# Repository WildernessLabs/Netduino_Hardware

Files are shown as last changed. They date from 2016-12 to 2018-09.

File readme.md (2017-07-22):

# Legacy Netduino 1, Mini, Netduino 2 and Netduino 3 Hardware Source Files

This repo contains the schematic and PCB design files for the legacy Netduino 1, Mini, Netduino 2 and Netduino 3 hardware:

* [Netduino 1](N1)
* [Netduino 1 Plus](N1_Plus)
* [Netduino Mini](Mini)
* [Netduino 2](N2)
* [Netduino Plus 2](N2_Plus)
* [Netduino 3](N3)
* [Netduino 3 w/Ethernet](N3_Ethernet)
* [Netduino 3 w/WiFi](N3_WiFi)
 
Each directory includes: 
 * `_ASSEMBLY` Directory - Files needed of a PCB assembler to instruct their "Pick and Place" machine to assemble the components on the PCB board. Also includes the Bill of Materials (BoM) for board.
 * `_FAB` Directory - Files necessary for a PCB fabricator to assembly the PCB, including the copper masks, silkscreen art, drill templates, etc.
 * `[model].pdf` - A PDF of the board design schematic.
 * `[model].brd` - The PCB design source file. Can be opened in Allegro Cadence, or similar.

# License
Copyright 2017, Wilderness Labs Inc.
    
    Licensed under the Apache License, Version 2.0 (the "License");
    you may not use this file except in compliance with the License.
    You may obtain a copy of the License at
    
      http://www.apache.org/licenses/LICENSE-2.0
    
    Unless required by applicable law or agreed to in writing, software
    distributed under the License is distributed on an "AS IS" BASIS,
    WITHOUT WARRANTIES OR CONDITIONS OF ANY KIND, either express or implied.
    See the License for the specific language governing permissions and
    limitations under the License.

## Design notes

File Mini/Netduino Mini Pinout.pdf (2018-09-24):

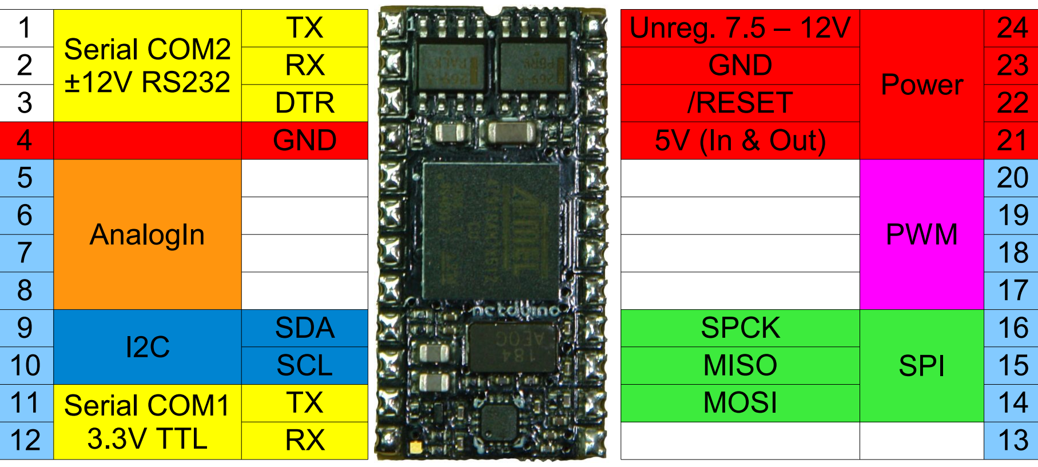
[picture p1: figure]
Unreg. 7.5 – 12V; Power; GND; DTR; /RESET; 5V (In & Out); AnalogIn; PWM; SDA; SPCK; SPI; SCL; MISO; MOSI; Serial COM2 ±12V RS232; Serial COM1 3.3V TTL

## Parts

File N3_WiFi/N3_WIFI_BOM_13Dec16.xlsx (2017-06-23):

Netduino 3 Wi-Fi Revised: Wednesday, February 25, 2015
CW0058 Revision: A
Bill Of Materials February 26,2015 22:46:41 | Page1
Item | Quantity | Reference | Manufacturer | Part Number | Description | Value | Task
1 | 1 | C1 | Murata Electronics North America | GRM31CR61A226ME19L | CAP CER 22UF 10V 20% X5R 1206 | 22uF
2 | 1 | C2 | Murata Electronics North America | GRM21BR61E106KA73L | CAP CER 10UF 25V 10% X5R 0805 | 10uF
3 | 3 | C4,C42,C47 | Murata Electronics North America | GRM21BR60J226ME39L | CAP CER 22UF 6.3V 20% X5R 0805 | 22uF
4 | 11 | C5,C6,C10,C11,C12,C13,C14,C22,C48,C49,C50 | Murata Electronics North America | GRM155R61A104KA01D | CAP CER 0.1UF 10V 10% X5R 0402 | 0.1uF
5 | 1 | C7 | Murata Electronics North America | GNM1M2R60J105ME12D | CAP ARRAY 1.0UF 6.3V X5R 0504 | 1uF
6 | 2 | C9, C53 | Murata Electronics North America | GRM033R61A104KE15D | CAP CER 0.1UF 10V X5R 0201 | 0.1uF | update
7 | 2 | C16,C17 | Murata Electronics North America | GRM155R60J225ME15D | CAP CER 2.2UF 6.3V 20% X5R 0402 | 2.2uF
8 | 2 | C18,C19 | Murata Electronics North America | GRM1555C1H180JA01D | CAP CER 18PF 50V 5% NP0 0402 | 18pF
9 | 1 | C20 | Murata Electronics North America | GRM155R71H472KA01D | CAP CER 4700PF 50V 10% X7R 0402 | 4.7nF
10 | 3 | C21,C51,C52 | Vishay | TR3C107K010C0100 | CAP TANT 100UF 10V 10% 2312 | 100uF
11 | 1 | C43 | AVX Corporation | F931A476MBA | CAP TANT 47UF 10V 1OHM 20% 1411 | 47uF
12 | 1 | C44 | Murata Electronics North America | GJM1555C1H1R0BB01D | CAP CER 1PF 50V NP0 0402 | 1pF
13 | 1 | D1 | Lite-On Inc | LTW-170TK | LED WHITE YELLOW 280MCD 0805 | WHITE
14 | 1 | D2 | Lite-On Inc | LTST-C170TBKT | LED BLUE CLEAR 0805 SMD | BLUE
15 | 1 | D3 | Micro Commerical Co | SS15E-TP | DIODE SCHOTTKY 50V 1A SMAE | SS15E-TP
16 | 1 | D4 | Littelfuse Inc | SP3003-04XTG | TVS ARRAY ESD 4CH 0.65PF SOT563 | SP3003-04XTG
17 | 3 | D5,D6,D7 | Lite-On Inc | LTST-C190TBKT | LED 468NM BLUE CLEAR 0603 SMD | BLUE
18 | 1 | D9 | Lite On | LTST-C295KGKSKT | LED GREEN YELLOW 0603 | LTST-C295KGKSKT
19 | 1 | F1 | Bourns Inc. | MF-NSMF075-2 | PTC RESETTABLE .75A 6V 1206 | MF-NSMF075-2
20 | 1 | J1 | ADAM TECH | ADC-043A-1 | CONN JACK POWER 2.1MM PCB | ADC-043A-1
21 | 2 | J2,J6 | Custom | HDR100IMP08F-G-V-TH-BLUE | CONN HEADER BLUE FEMALE 8POS .1" GOLD | HDR100IMP08F-G-V-TH-BLUE
22 | 1 | J3 | Custom | HDR100IMP10F-G-V-TH-BLUE | CONN HEADER BLUE FEMALE 10POS .1" GOLD | HDR100IMP10F-G-V-TH-BLUE
23 | 1 | J4 | Custom | HDR100IMP06F-G-V-TH-BLUE | CONN HEADER BLUE FEMALE 6POS .1" GOLD | HDR100IMP06F-G-V-TH-BLUE
24 | 1 | J5 | JAE Electronics | DX4R005JJ2R1800 | CONN RCPT MICRO USB 2.0 B | DX4R005JJ2R1800
25 | 1 | J7 | FCI | 67996-206HLF | CONN HEADER 6POS .100 STR 15AU | 67996-206HLF
26 | 1 | J8 |  | MINI_JTAG_SMD | MINI JTAG CONN HEADER 10POS UNSHD VERT SMD | MINI_JTAG_SMD | DO NOT PLACE
27 | 1 | J9 | Hirose Electric Co Ltd | DM3AT-SF-PEJM5 | CONN MICRO SD R/A PUSH-PUSH SMD | DM3AT-SF-PEJM5
28 | 3 | J10,J11,J12 | SECRET LABS | HDR050IDC10MS2-G-V-SM-BLUE | GOPORT SOCKET BLUE IDC | HDR050IDC10MS2-G-V-SM-BLUE
29 | 1 | J13 | Taiyo Yuden | AH316M245001-T | ANT BLUETOOTH W-LAN ZIGBEE WIMAX | AH316M245001-T
30 | 1 | L1 | Murata Electronics North America | LQH3NPN2R2NM0L | INDUCTOR 2.2UH 1.6A 30% 1212 | 2.2uH
31 | 1 | L2 | Murata Electronics North America | BLM15AX102SN1D | FERRITE CHIP 1000 OHM 0402 | BEAD
32 | 1 | L3 | Murata Electronics North America | LQP15MN3N6B02D | FIXED IND 3.6NH 170MA 500 MOHM | 3.6nH
33 | 6 | Q1,Q2,Q6,Q10,Q11,Q12 | ON Semiconductor | MUN5215DW1T1G | TRANS PREBIAS 10K 50V DUAL NPN SOT363 | MUN5215DW1T1G
34 | 1 | Q3 | ON Semiconductor | NTR4101PT1G | MOSFET P-CH 20V 1.8A SOT-23 | NTR4101PT1G
35 | 5 | Q4,Q5,Q7,Q8,Q9 | ON Semiconductor | NTJD4152PT1G | MOSFET 2P-CH 20V 880MA SOT-363 | NTJD4152PT1G
36 | 1 | R1 | Panasonic - ECG | EXB-N8V102JX | RES ARRAY 1K OHM 4 RES 0804 | 1K
37 | 1 | R3 | Panasonic - ECG | ERJ-2GEJ152X | RES 1.5K OHM 1/10W 5% 0603 SMD | 1.5K | Update
38 | 5 | R4,R5,R11,R12,R14 | Panasonic - ECG | EXB-N8V103JX | RES ARRAY 10K OHM 4 RES 0804 | 10K
39 | 1 | R6 | Panasonic - ECG | ERJ-2RKF1542X | RES 15.4K OHM 1/10W 1% 0402 SMD | 15.4K
40 | 1 | R7 | Panasonic - ECG | ERJ-2GEJ391X | RES 390 OHM 1/10W 5% 0402 SMD | 390
41 | 1 | R8 | Panasonic - ECG | EXB-24V104JX | RES ARRAY 100K OHM 2 RES 0404 | 100K
42 | 1 | R9 | Panasonic - ECG | EXB-24V220JX | RES ARRAY 22 OHM 2 RES 0404 | 22
43 | 1 | R10 | Panasonic - ECG | ERJ-2RKF1004X | RES 1.00M OHM 1/10W 1% 0402 SMD | 1M
44 | 1 | R13 | Panasonic - ECG | EXB-24V103JX | RES ARRAY 10K OHM 2 RES 0404 | 10K
45 | 1 | R15 | Panasonic - ECG | EXB-N8V681JX | RES ARRAY 680 OHM 4 RES 0804 | 680
46 | 1 | R16 | Panasonic - ECG | EXB-24V152JX | RES ARRAY 1.5K OHM 2 RES 0404 | 1.5K
47 | 1 | R18 | Panasonic - ECG | ERJ-2RKF1003X | RES 100K OHM 1/10W 1% 0402 SMD | 100K
48 | 1 | SW1 | HUA-JIE | TSXH-2GL | SWITCH TACTILE SPST-NO | TSXH-2GL
49 | 1 | U1 | Texas Instruments | LM3671MF-3.3/NOPB | IC REG BUCK SYNC 3.3V SOT23-5 | LM3671MF-3.3/NOPB
50 | 1 | U2 | Texas Instruments | TLV1117-50IKVURG3 | IC REG LDO 5V 0.8A TO252-3 | TLV1117-50IKVURG3
51 | 1 | U3 | Texas Instruments | LMV321IDCKR | IC OPAMP GP 1MHZ RRO SC70-5 | LMV321IDCKR
52 | 1 | U4 | STMicroelectronics | STM32F427VIT6 | IC MCU ARM 2MB FLASH 100LQFP | STM32F427VIT6
53 | 1 | U5 | Texas Instruments | CC3100MOD | MODULE WI-FI NETWORK PROCESSOR | CC3100MOD
54 | 1 | Y1 | Abracon Corporation | ABM7-25.000MHZ-D2Y-T | CRYSTAL 25.000 MHZ 18PF SMD | 25.000MHz

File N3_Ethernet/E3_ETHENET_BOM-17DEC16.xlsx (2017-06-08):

Netduino 3 Ethernet Revised: Monday, January 12, 2015
CW0053 Revision: A
Bill Of Materials January 15,2015 13:19:47 | Page1
Item | Quantity | Reference | Manufacturer | Part Number | Description | Value | Notes
1 | 1 | C1 | Murata Electronics North America | GRM31CR61A226ME19L | CAP CER 22UF 10V 20% X5R 1206 | 22uF
2 | 1 | C2 | Murata Electronics North America | GRM21BR61E106KA73L | CAP CER 10UF 25V 10% X5R 0805 | 10uF
3 | 4 | C4,C23,C25,C42 | Murata Electronics North America | GRM21BR60J226ME39L | CAP CER 22UF 6.3V 20% X5R 0805 | 22uF
4 | 10 | C5,C6,C10,C11,C12,C13,C14,C22,C29,C33 | Murata Electronics North America | GRM155R61A104KA01D | CAP CER 0.1UF 10V 10% X5R 0402 | 0.1uF
5 | 1 | C7 | Murata Electronics North America | GNM1M2R60J105ME12D | CAP ARRAY 1.0UF 6.3V X5R 0504 | 1uF
6 | 16 | C9,C24,C26,C30,C31,C32,C35,C39, C44,C45,C46,C47,C48,C49,C50,C51 | Murata Electronics North America | GRM033R61A104KE15D (http://www.mouser.com/ProductDetail/Murata-Electronics/GRM033R61A104KE15D/) | CAP CER 0.1UF 10V X5R 0201 | 0.1uF
7 | 2 | C16,C17 | Murata Electronics North America | GRM155R60J225ME15D | CAP CER 2.2UF 6.3V 20% X5R 0402 | 2.2uF
8 | 4 | C18,C19,C37,C38 | Murata Electronics North America | GRM1555C1H180JA01D | CAP CER 18PF 50V 5% NP0 0402 | 18pF
9 | 1 | C20 | Murata Electronics North America | GRM155R71H472KA01D | CAP CER 4700PF 50V 10% X7R 0402 | 4.7nF
10 | 1 | C21 | Vishay | TR3C107K010C0100 | CAP TANT 100UF 10V 10% 2312 | 100uF
11 | 3 | C27,C34,C36 | Murata Electronics North America | GRM188R60J475KE19D | CAP CER 4.7UF 6.3V 10% X5R 0603 | 4.7uF
12 | 1 | C28 | Murata Electronics North America | GRM155R61A105KE15D | CAP CER 1UF 10V 10% X5R 0402 | 1uF
13 | 1 | C40 | AVX Corporation | 1206GC102KAT1A | CAP CERM 1000PF 2000V X7R 1206 | 1nF
14 | 1 | C41 | Murata Electronics North America | GRM21BR71H104KA01L | CAP CER 0.1UF 50V 10% X7R 0805 | 0.1uF
15 | 1 | C43 | AVX Corporation | F931A476MBA | CAP TANT 47UF 10V 1OHM 20% 1411 | 47uF
16 | 1 | D1 | Lite-On Inc | LTW-170TK | LED WHITE YELLOW 280MCD 0805 | WHITE
17 | 1 | D2 | Lite-On Inc | LTST-C170TBKT | LED BLUE CLEAR 0805 SMD | BLUE
18 | 1 | D3 | Micro Commerical Co | SS15E-TP | DIODE SCHOTTKY 50V 1A SMAE | SS15E-TP
19 | 2 | D4,D8 | Littelfuse Inc | SP3003-04XTG | TVS ARRAY ESD 4CH 0.65PF SOT563 | SP3003-04XTG
20 | 3 | D5,D6,D7 | Lite-On Inc | LTST-C190TBKT | LED 468NM BLUE CLEAR 0603 SMD | BLUE
21 | 1 | D9 | Lite On | LTST-C295KGKSKT | LED GREEN YELLOW 0603 | LTST-C295KGKSKT
22 | 1 | F1 | Bourns Inc. | MF-NSMF075-2 | PTC RESETTABLE .75A 6V 1206 | MF-NSMF075-2
23 | 1 | J1 | ADAM TECH | ADC-043A-1 | CONN JACK POWER 2.1MM PCB | ADC-043A-1
24 | 2 | J2,J6 | Custom | HDR100IMP08F-G-V-TH-BLUE | CONN HEADER BLUE FEMALE 8POS .1" GOLD | HDR100IMP08F-G-V-TH-BLUE
25 | 1 | J3 | Custom | HDR100IMP10F-G-V-TH-BLUE | CONN HEADER BLUE FEMALE 10POS .1" GOLD | HDR100IMP10F-G-V-TH-BLUE
26 | 1 | J4 | Custom | HDR100IMP06F-G-V-TH-BLUE | CONN HEADER BLUE FEMALE 6POS .1" GOLD | HDR100IMP06F-G-V-TH-BLUE
27 | 1 | J5 | JAE Electronics | DX4R005JJ2R1800 | CONN RCPT MICRO USB 2.0 B | DX4R005JJ2R1800
28 | 1 | J7 | FCI | 67996-206HLF | CONN HEADER 6POS .100 STR 15AU | 67996-206HLF | DO NOT PLACE
29 | 1 | J8 |  | MINI_JTAG_SMD | MINI JTAG CONN HEADER 10POS UNSHD VERT SMD | MINI_JTAG_SMD | DO NOT PLACE
30 | 1 | J9 | Hirose Electric Co Ltd | DM3AT-SF-PEJM5 | CONN MICRO SD R/A PUSH-PUSH SMD | DM3AT-SF-PEJM5
31 | 3 | J10,J11,J12 | SECRET LABS | HDR050IDC10MS2-G-V-SM-BLUE | GOPORT SOCKET BLUE IDC | HDR050IDC10MS2-G-V-SM-BLUE
32 | 1 | J13 | Molex | 44661-0002 | CONN MOD JACK R/A 8P8C UNSHIELDED | 44661-0002
33 | 1 | L1 | Murata Electronics North America | LQH3NPN2R2NM0L | INDUCTOR 2.2UH 1.6A 30% 1212 | 2.2uH
34 | 4 | L2,L3,L4,L5 | Murata Electronics North America | BLM15AX102SN1D | FERRITE CHIP 1000 OHM 0402 | BEAD
35 | 5 | Q1,Q2,Q6,Q10,Q11 | ON Semiconductor | MUN5215DW1T1G | TRANS PREBIAS 10K 50V DUAL NPN SOT363 | MUN5215DW1T1G
36 | 1 | Q3 | ON Semiconductor | NTR4101PT1G | MOSFET P-CH 20V 1.8A SOT-23 | NTR4101PT1G
37 | 5 | Q4,Q5,Q7,Q8,Q9 | ON Semiconductor | NTJD4152PT1G | MOSFET 2P-CH 20V 880MA SOT-363 | NTJD4152PT1G
38 | 1 | R1 | Panasonic - ECG | EXB-N8V102JX | RES ARRAY 1K OHM 4 RES 0804 | 1K
39 | 1 | R3 | Panasonic - ECG | ERJ-3EKF1501V (http://www.mouser.com/ProductDetail/Panasonic/ERJ-3EKF1501V/?qs=H7k1u0Mp9JTu8xEF0m60uQ%3D%3D) | RES 1.5K OHM 1/10W 1% 0603 SMD | 1.5K
40 | 6 | R4,R5,R11,R12,R14,R19 | Panasonic - ECG | EXB-N8V103JX | RES ARRAY 10K OHM 4 RES 0804 | 10K
41 | 1 | R6 | Panasonic - ECG | ERJ-2RKF1542X | RES 15.4K OHM 1/10W 1% 0402 SMD | 15.4K
42 | 1 | R7 | Panasonic - ECG | ERJ-2GEJ391X | RES 390 OHM 1/10W 5% 0402 SMD | 390
43 | 1 | R8 | Panasonic - ECG | EXB-24V104JX | RES ARRAY 100K OHM 2 RES 0404 | 100K
44 | 1 | R9 | Panasonic - ECG | EXB-24V220JX | RES ARRAY 22 OHM 2 RES 0404 | 22
45 | 3 | R10,R16,R20 | Panasonic - ECG | ERJ-2RKF1004X | RES 1.00M OHM 1/10W 1% 0402 SMD | 1M
46 | 1 | R13 | Panasonic - ECG | EXB-24V103JX | RES ARRAY 10K OHM 2 RES 0404 | 10K
47 | 1 | R15 | Panasonic - ECG | EXB-N8V681JX | RES ARRAY 680 OHM 4 RES 0804 | 680
48 | 1 | R17 | Vishay Dale | CRA06S08349R9FTA | RES ARRAY 49.9 OHM 4 RES 1206 | 49.9
49 | 1 | R18 | Vishay Dale | CRA06S08375R0FTA | RES ARRAY 75 OHM 4 RES 1206 | 75
50 | 1 | R21 | Panasonic - ECG | ERJ-2RKF1212X | RES 12.1K OHM 1/10W 1% 0402 SMD | 12.1K
51 | 1 | R22 | Panasonic - ECG | EXB-24V152JX | RES ARRAY 1.5K OHM 2 RES 0404 | 1.5K
52 | 1 | SW1 | HUA-JIE | TSXH-2GL | SWITCH TACTILE SPST-NO | TSXH-2GL
53 | 1 | T1 | Pulse | HX1198NLT | MODULE XFRMR SGL ETHR LAN 16SOIC | HX1198NLT
54 | 1 | U1 | Texas Instruments | LM3671MF-3.3/NOPB | IC REG BUCK SYNC 3.3V SOT23-5 | LM3671MF-3.3/NOPB
55 | 1 | U2 | Texas Instruments | TLV1117-50IKVURG3 | IC REG LDO 5V 0.8A TO252-3 | TLV1117-50IKVURG3
56 | 1 | U3 | Texas Instruments | LMV321IDCKR | IC OPAMP GP 1MHZ RRO SC70-5 | LMV321IDCKR
57 | 1 | U4 | STMicroelectronics | STM32F427VIT6 | IC MCU ARM 2MB FLASH 100LQFP | STM32F427VIT6
58 | 1 | U5 | Asix | AX88796CLF | Low-Power SPI or Non-PCI Ethernet Controller | AX88796CLF
59 | 2 | Y1,Y2 | Abracon Corporation | ABM7-25.000MHZ-D2Y-T | CRYSTAL 25.000 MHZ 18PF SMD | 25.000MHz

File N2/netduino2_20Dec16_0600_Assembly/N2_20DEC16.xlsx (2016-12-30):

Netduino 2 Revised: 20DEC2016
CW0035 Revision: A
Bill Of Materials October 16,2012 13:13:13 | Page1
Item | Quantity | Reference | Manufacturer | Part Number | Description | Task
______________________________________________
1 | 1 | C1 | Murata Electronics North America | GRM21BR71H474KA88L | CAP CER 0.47UF 50V 10% X7R 0805
2 | 9 | C2,C5,C6,C7,C8,C15,C16,C17,C26 | Murata Electronics North America | GRM31CR71A106KA01L | CAP CER 10UF 10V 10% X7R 1206
3 | 10 | C3,C4,C9,C10,C11,C12,C13,C14,C20,C22 | Murata Electronics North America | GRM188R71C104KA01D | CAP CER 0.1UF 16V 10% X7R 0603
4 | 2 | C18,C19 | Murata Electronics North America | GRM21BR71A225KA01L | CAP CER 2.2UF 10V 10% X7R 0805
5 | 1 | C21 | Murata Electronics North America | GRM21BR71A105KA01L | CAP CER 1UF 10V 10% X7R 0805
6 | 2 | C23,C24 | Murata Electronics North America | GRM1885C1H180JA01D | CAP CER 18PF 50V 5% NP0 0603
7 | 1 | C25 | Vishay | TR3C107K010C0100 | CAP TANT 100UF 10V 10% 2312
8 | 1 | D1 | Micro Commerical Co | SS15-TP | DIODE SCHOTTKY 1A 50V SMA
9 | 1 | D2 | Lite-On Inc | LTW-170TK | LED WHITE YELLOW 280MCD 0805
10 | 1 | D3 | Lite-On Inc | LTST-C170TBKT | LED BLUE CLEAR 0805 SMD
11 | 3 | D4,D5,D6 | Littelfuse Inc | PGB1010402KR | SUPPRESSOR ESD 12VDC 0402 SMD
12 | 1 | F1 | Littelfuse | 1206L050YR | THERMISTOR PTC 6V .50A RESETTABLE
13 | 1 | J1 | ADAM TECH | ADC-002A-1 | CONN JACK POWER 2.1MM PCB
14 | 2 | J2,J6 | Custom | HDR100IMP08F-G-V-TH-BLUE | CONN HEADER BLUE FEMALE 8POS .1" GOLD
15 | 1 | J3 | Hirose | 656-DX4R005JJ2R1800 (http://www.mouser.com/ProductDetail/JAE-Electronics/DX4R005JJ2R1800/?qs=ckml%252bxrUdjTvILfne%252b8EpQ%3D%3D) | Micro USB 2.0 Type B Connectors | Updated
16 | 1 | J4 | Custom | HDR100IMP10F-G-V-TH-BLUE | CONN HEADER BLUE FEMALE 10POS .1" GOLD
17 | 1 | J5 | Custom | HDR100IMP06F-G-V-TH-BLUE | CONN HEADER BLUE FEMALE 6POS .1" GOLD
18 | 1 | L1 | Murata Electronics North America | LQH3NPN2R2NM0L | INDUCTOR 2.2UH 1.6A 30% SMD
19 | 1 | Q1 | ON Semiconductor | MMBT3906TT1G | TRANS PNP GP 40V 200MA SC75-3
20 | 2 | Q2,Q3 | ON Semiconductor | MBT3904DW1T1G | TRANS NPN DUAL 40V 200MA SOT-363
21 | 1 | Q4 | ON Semiconductor | NTR4101PT1G | MOSFET P-CH 20V 1.8A SOT-23
22 | 1 | Q5 | ON Semiconductor | NTJD4152PT1G | MOSFET 2P-CH 20V 880MA SOT-363
23 | 1 | R2 | Panasonic - ECG | ERJ-3EKF1501V | RES 1.50K OHM 1/10W 1% 0603 SMD
24 | 1 | R3 | Panasonic ECG | ERJ-6GEYJ1R0V | RESISTOR 1.0 OHM 1/8W 5% 0805
25 | 3 | R4,R11,R12 | Panasonic - ECG | EXB-N8V103JX (http://www.mouser.com/ProductDetail/Panasonic/EXB-N8V103JX/?qs=u8huD7HxK6bNr8tqvNkAOQ%3D%3D) | RES ARRAY 10K OHM 4 RES 0804 | Updated
26 | 1 | R6 | Panasonic - ECG | ERJ-3EKF1001V | RES 1.00K OHM 1/10W 1% 0603 SMD
27 | 1 | R8 | Panasonic - ECG | ERJ-2RKF1402X (http://www.mouser.com/ProductDetail/Panasonic/ERJ-2RKF1402X/?qs=MVjVSMjNRMrMgFTFLdW36A%3D%3D) | RES 14.0K OHM 1/10W 1% 0402 SMD | Updated
28 | 1 | R9 | Panasonic - ECG | ERJ-2RKF1623X (http://www.mouser.com/ProductDetail/Panasonic/ERJ-2RKF1623X/?qs=xvTjQbhLFHK1fJJgOidlhQ%3D%3D) | RES 162K OHM 1/10W 1% 0402 SMD
29 | 1 | R10 | Panasonic - ECG | ERJ-2RKF3602X (http://www.mouser.com/ProductDetail/Panasonic/ERJ-2RKF3602X/?qs=YMBIwoNQYdWglRbBHPFpuA%3D%3D) | RES 36.0K OHM 1/10W 1% 0402 SMD | Updated
30 | 1 | R13 | Panasonic - ECG | ERJ-2GEJ391X (http://www.mouser.com/ProductDetail/Panasonic/ERJ-2GEJ391X/?qs=H7k1u0Mp9JQHgGq8tq8dsw%3D%3D) | RES 390 OHM 1/10W 5% 0402 SMD | Updated
31 | 1 | R14 | Panasonic - ECG | EXB-24V220JX (http://www.mouser.com/ProductDetail/Panasonic/EXB-24V220JX/?qs=oE3VwAv%2FYtkKhK0m4TkqFQ%3D%3D) | RES ARRAY 22 OHM 2 RES 0404 | Updated
32 | 4 | R27,R28,R31,R32 | Panasonic - ECG | ERJ-3EKF1002V | RES 10.0K OHM 1/10W 1% 0603 SMD
33 | 1 | SW1 | HUA-JIE | TSXH-2GL | SWITCH TACTILE SPST-NO | Updated
34 | 1 | U1 | ON Semiconductor | MC33269DT-5.0G | IC REG LDO 800MA 5V DPAK
35 | 1 | U2 | STMicroelectronics | ST1S12GR | IC BUCK SYNC ADJ 0.7A TSOT23
36 | 1 | U3 | National Semiconductor | LMV7271MF/NOPB | IC COMP 1.8V SNGL R-R IN SOT23-5
37 | 1 | U4 | STMicroelectronics | STM32F205RFT6 | MCU ARM 768KB FLASH 64LQFP
38 | 1 | Y1 | Abracon Corporation | ABM3B-25.000MHZ-D2Y-T | CRYSTAL 25.000 MHZ 18PF SMD

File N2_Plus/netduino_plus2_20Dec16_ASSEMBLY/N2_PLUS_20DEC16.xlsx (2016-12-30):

Netduino Plus 2 Revised: December 20 2016
CW0034 Revision: A
Bill Of Materials September 28,2012 9:20:16 | Page1
Item | Quantity | Reference | Manufacturer | Part Number | Description | Task
______________________________________________
1 | 1 | C1 | Murata Electronics North America | GRM21BR71H474KA88L | CAP CER 0.47UF 50V 10% X7R 0805
2 | 11 | C2,C5,C6,C7,C8,C15,C16,C17,C26,C27,C34 | Murata Electronics North America | GRM31CR71A106KA01L | CAP CER 10UF 10V 10% X7R 1206
3 | 18 | C3,C4,C9,C10,C11,C12,C13,C14,C20,C22,C28,C29,C30,C31,C32,C33,C35,C36 | Murata Electronics North America | GRM155R61A104KA01D | CAP CER 0.1UF 10V 10% X5R 0402
4 | 2 | C18,C19 | Murata Electronics North America | GRM21BR71A225KA01L | CAP CER 2.2UF 10V 10% X7R 0805
5 | 1 | C21 | Murata Electronics North America | GRM155R60J105KE19D | CAP CER 1UF 6.3V 10% X5R 0402
6 | 2 | C23,C24 | Murata | GRM1555C1H180JA01D (http://www.mouser.com/ProductDetail/Murata-Electronics/GRM1555C1H180JA01D/?qs=mRkWMvdT7ZKEkI5QPHEfww%3D%3D) | CAP CER 18PF 50V 5% NP0 0402 | updated
7 | 1 | C25 | Vishay | TR3C107K010C0100 | CAP TANT 100UF 10V 10% 2312
8 | 1 | C37 | AVX Corporation | 1206GC102KAT1A | CAP CERM 1000PF 2000V X7R 1206
9 | 1 | D1 | Micro Commerical Co | SS15-TP | DIODE SCHOTTKY 1A 50V SMA
10 | 1 | D2 | Lite-On Inc | LTW-170TK | LED WHITE YELLOW 280MCD 0805
11 | 1 | D3 | Lite-On Inc | LTST-C170TBKT | LED BLUE CLEAR 0805 SMD
12 | 3 | D4,D5,D6 | Littelfuse Inc | PGB1010402KR | SUPPRESSOR ESD 12VDC 0402 SMD
13 | 1 | D7 | Lite-On Inc | LTST-C190KGKT | LED GREEN CLEAR 0603 SMD
14 | 1 | F1 | Littelfuse | 1206L050YR | THERMISTOR PTC 6V .50A RESETTABLE
15 | 1 | J1 | ADAM TECH | ADC-043A-1 | CONN JACK POWER 2.1MM PCB
16 | 2 | J2,J6 | Custom | HDR100IMP08F-G-V-TH-BLUE | CONN HEADER BLUE FEMALE 8POS .1" GOLD
17 | 1 | J3 | JAE Electronics | 656-DX4R005JJ2R1800 (http://www.mouser.com/ProductDetail/JAE-Electronics/DX4R005JJ2R1800/?qs=ckml%252bxrUdjTvILfne%252b8EpQ%3D%3D) | Micro USB 2.0 Type B Connectors | updated
18 | 1 | J4 | Custom | HDR100IMP10F-G-V-TH-BLUE | CONN HEADER BLUE FEMALE 10POS .1" GOLD
19 | 1 | J5 | Custom | HDR100IMP06F-G-V-TH-BLUE | CONN HEADER BLUE FEMALE 6POS .1" GOLD
20 | 1 | J7 | DO NOT PLACE | MINI_JTAG | Mini JTAG Connector TH Vertical
21 | 1 | J8 | Hirose Electric Co Ltd | DM3AT-SF-PEJ | CONN MICRO SD R/A PUSH-PUSH SMD
22 | 1 | J9 | Molex | 44661-0002 | CONN MODULAR JACK RT/ANG 8-8
23 | 1 | L1 | Murata Electronics North America | LQH3NPN2R2NM0L | INDUCTOR 2.2UH 1.6A 30% SMD
24 | 1 | L2 | Murata | BLM15AX102SN1D (http://www.mouser.com/ProductDetail/Murata-Electronics/BLM15AX102SN1D/?qs=MY6wChARw2zFsmOR09MDxg%3D%3D) | FERRITE CHIP 1000 OHM 0402 | updated
25 | 1 | Q1 | ON Semiconductor | MMBT3906TT1G | TRANS PNP GP 40V 200MA SC75-3
26 | 2 | Q2,Q3 | ON Semiconductor | MBT3904DW1T1G | TRANS NPN DUAL 40V 200MA SOT-363
27 | 1 | Q4 | ON Semiconductor | NTR4101PT1G | MOSFET P-CH 20V 1.8A SOT-23
28 | 2 | Q5,Q6 | ON Semiconductor | NTJD4152PT1G | MOSFET 2P-CH 20V 880MA SOT-363
29 | 2 | R2,R16 | Panasonic - ECG | ERJ-3EKF1501V (http://www.mouser.com/ProductDetail/Panasonic/ERJ-3EKF1501V/?qs=H7k1u0Mp9JTu8xEF0m60uQ%3D%3D) | RES 1.5K OHM 1/10W 1% 0603 SMD | updated
30 | 1 | R3 | Panasonic ECG | ERJ-6GEYJ1R0V | RESISTOR 1.0 OHM 1/8W 5% 0805
31 | 4 | R4,R7,R11,R12 | Panasonic - ECG | EXB-N8V103JX | RES ARRAY 10K OHM 4 RES 0804
32 | 6 | R5,R15,R26,R27,R28,R31 | Panasonic - ECG | ERJ-3EKF1002V (http://www.mouser.com/ProductDetail/Panasonic/ERJ-3EKF1002V/?qs=H7k1u0Mp9JSrGPQ5%2F5COuw%3D%3D) | RES 10.0K OHM 1/10W 1% 0603 SMD | updated
33 | 1 | R6 | Panasonic - ECG | ERJ-3EKF1001V (http://www.mouser.com/ProductDetail/Panasonic/ERJ-3EKF1001V/?qs=H7k1u0Mp9JTM8yQxOuvoDg%3D%3D) | RES 1.00K OHM 1/10W 1% 0603 SMD | updated
34 | 1 | R8 | Panasonic - ECG | ERJ-2RKF1402X | RES 14.0K OHM 1/10W 1% 0402 SMD
35 | 1 | R9 | Panasonic - ECG | ERJ-2RKF1623X | RES 162K OHM 1/10W 1% 0402 SMD
36 | 1 | R10 | Panasonic - ECG | ERJ-2RKF3602X | RES 36.0K OHM 1/10W 1% 0402 SMD
37 | 1 | R13 | Panasonic - ECG | ERJ-2GEJ391X | RES 390 OHM 1/10W 5% 0402 SMD
38 | 1 | R14 | Panasonic - ECG | EXB-24V220JX | RES ARRAY 22 OHM 2 RES 0404
39 | 1 | R17 | Panasonic - ECG | ERJ-2RKF2321X | RES 2.32K OHM 1/10W 1% 0402 SMD
40 | 4 | R18,R19,R20,R21 | Panasonic - ECG | ERJ-2RKF49R9X | RES 49.9 OHM 1/10W 1% 0402 SMD
41 | 4 | R22,R23,R24,R25 | Panasonic - ECG | ERJ-2RKF75R0X | RES 75.0 OHM 1/10W 1% 0402 SMD
42 | 1 | R30 | Panasonic - ECG | ERJ-2GEJ330X | RES 33 OHM 1/10W 5% 0402 SMD
43 | 1 | SW1 | HUA-JIE | TSXH-2GL | SWITCH TACTILE SPST-NO | updated
44 | 1 | T1 | Pulse | HX1198NL | MODULE XFRMR SGL ETHR LAN 16SOIC
45 | 1 | U1 | ON Semiconductor | MC33269DT-5.0G | IC REG LDO 800MA 5V DPAK
46 | 1 | U2 | STMicroelectronics | ST1S12GR | IC BUCK SYNC ADJ 0.7A TSOT23
47 | 1 | U3 | National Semiconductor | LMV7271MF/NOPB | IC COMP 1.8V SNGL R-R IN SOT23-5
48 | 1 | U4 | STMicroelectronics | STM32F405RGT6 | IC MCU 32BIT 1MB FLASH 64LQFP
49 | 1 | U5 | Microchip Technology | ENC28J60T-I/SS | IC ETHERNET CTLR SPI 28SSOP
50 | 1 | Y1 | Abracon Corporation | ABM7-25.000MHZ-D2Y-T | CRYSTAL 25.000 MHZ 18PF SMD
51 | 3 | MT1,MT2,MT3 | DO NOT PLACE

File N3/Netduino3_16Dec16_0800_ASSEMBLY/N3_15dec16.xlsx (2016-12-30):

Netduino 3 Revised: Wednesday, June 03, 2015
CW0057 Revision: A
Bill Of Materials June 3,2015 10:28:26 | Page1
Item | Quantity | Reference | Manufacturer | Part Number | Description | Value | Task
1 | 1 | C1 | Murata Electronics North America | GRM31CR61A226ME19L | CAP CER 22UF 10V 20% X5R 1206 | 22uF
2 | 1 | C2 | Murata Electronics North America | GRM21BR61E106KA73L | CER CAP 10UF 25V 10% X5R 0805 | 10uF | Updated
3 | 2 | C4,C42 | Murata Electronics North America | GRM21BR60J226ME39L | CAP CER 22UF 6.3V 20% X5R 0805 | 22uF
4 | 9 | C5,C6,C10,C11,C12,C13,C14,C46,C47 | Murata Electronics North America | GRM188R71C104KA01D | CAP CER 0.1UF 16V 10% X7R 0603 | 0.1uF
5 | 2 | C16,C17 | Murata Electronics North America | GRM188R61C225KE15D | CAP CER 2.2UF 16V 10% X5R 0603 | 2.2uF
6 | 2 | C18,C19 | Murata Electronics North America | GRM1885C1H180JA01D | CAP CER 18PF 50V 5% NP0 0603 | 18pF
7 | 1 | C20 | Murata Electronics North America | GRM155R71H472KA01D | CAP CER 4700PF 50V 10% X7R 0402 | 4.7nF | Updated
8 | 1 | C21 | Vishay | TR3C107K010C0100 | CAP TANT 100UF 10V 10% 2312 | 100uF
9 | 1 | C43 | AVX Corporation | F931A476MBA | CAP TANT 47UF 10V 1OHM 20% 1411 | 47uF
10 | 2 | C44,C45 | Murata Electronics North America | GRM155R61A105KE15D | CAP CER 1UF 10V 10% X5R 0402 | 1uF | Updated
11 | 1 | D1 | Lite-On Inc | LTW-170TK | LED WHITE YELLOW 280MCD 0805 | WHITE
12 | 1 | D2 | Lite-On Inc | LTST-C170TBKT | LED BLUE CLEAR 0805 SMD | BLUE
13 | 1 | D3 | Micro Commerical Co | SS15E-TP | DIODE SCHOTTKY 50V 1A SMAE | SS15E-TP
14 | 1 | D4 | Littelfuse Inc | SP3003-04XTG | TVS ARRAY ESD 4CH 0.65PF SOT563 | SP3003-04XTG
15 | 3 | D5,D6,D7 | Lite-On Inc | LTST-C190TBKT | LED 468NM BLUE CLEAR 0603 SMD | BLUE
16 | 1 | F1 | Bourns Inc. | MF-NSMF075-2 | PTC RESETTABLE .75A 6V 1206 | MF-NSMF075-2
17 | 1 | J1 | ADAM TECH | ADC-002A-1 | CONN JACK POWER 2.1MM PCB | ADC-002A-1
18 | 2 | J2,J6 | Custom | HDR100IMP08F-G-V-TH-BLUE | CONN HEADER BLUE FEMALE 8POS .1" GOLD | HDR100IMP08F-G-V-TH-BLUE
19 | 1 | J3 | Custom | HDR100IMP10F-G-V-TH-BLUE | CONN HEADER BLUE FEMALE 10POS .1" GOLD | HDR100IMP10F-G-V-TH-BLUE
20 | 1 | J4 | Custom | HDR100IMP06F-G-V-TH-BLUE | CONN HEADER BLUE FEMALE 6POS .1" GOLD | HDR100IMP06F-G-V-TH-BLUE
21 | 1 | J5 | JAE Electronics | DX4R005JJ2R1800 | CONN RCPT MICRO USB 2.0 B | DX4R005JJ2R1800
22 | 1 | J8 |  | MINI_JTAG_SMD | MINI JTAG CONN HEADER 10POS UNSHD VERT SMD | MINI_JTAG_SMD
23 | 3 | J10,J11,J12 | SECRET LABS | HDR050IDC10MS2-G-V-SM-BLUE | GOPORT SOCKET BLUE IDC | HDR050IDC10MS2-G-V-SM-BLUE
24 | 1 | L1 | Murata Electronics North America | LQH3NPN2R2NM0L | INDUCTOR 2.2UH 1.6A 30% 1212 | 2.2uH
25 | 1 | L2 | Murata Electronics North America | BLM15AX102SN1D (http://www.mouser.com/ProductDetail/Murata-Electronics/BLM15AX102SN1D/?qs=MY6wChARw2zFsmOR09MDxg%3D%3D) | FERRITE CHIP 1000 OHM 0402 | BEAD | Updated
26 | 5 | Q1,Q2,Q6,Q10,Q11 | ON Semiconductor | MUN5215DW1T1G | TRANS PREBIAS 10K 50V DUAL NPN SOT363 | MUN5215DW1T1G
27 | 1 | Q3 | ON Semiconductor | NTR4101PT1G | MOSFET P-CH 20V 1.8A SOT-23 | NTR4101PT1G
28 | 5 | Q4,Q5,Q7,Q8,Q9 | ON Semiconductor | NTJD4152PT1G | MOSFET 2P-CH 20V 880MA SOT-363 | NTJD4152PT1G
29 | 1 | R1 | Panasonic - ECG | EXB-N8V102JX (http://www.mouser.com/ProductDetail/Panasonic/EXB-N8V102JX/?qs=cttFivMKqWw%252bAry%2FRRDGuA%3D%3D) | RES ARRAY 1K OHM 4 RES 0804 | 1K | Updated
30 | 1 | R3 | Panasonic - ECG | ERJ-3EKF1501V | RES 1.50K OHM 1/10W 1% 0603 SMD | 1.5K
31 | 4 | R4,R5,R12,R14 | Panasonic - ECG | EXB-V8V103JV | RES ARRAY 10K OHM 4 RES 1206 | 10K
32 | 1 | R6 | Panasonic - ECG | ERJ-2RKF1542X (http://www.mouser.com/ProductDetail/Panasonic/ERJ-2RKF1542X/?qs=MVjVSMjNRMqQLC1RUffyYw%3D%3D) | RES 15.4K OHM 1/10W 1% 0402 SMD | 15.4K | Updated
33 | 1 | R7 | Panasonic - ECG | ERJ-2GEJ391X (http://www.mouser.com/ProductDetail/Panasonic/ERJ-2GEJ391X/?qs=H7k1u0Mp9JQHgGq8tq8dsw%3D%3D) | RES 390 OHM 1/10W 5% 0402 SMD | 390 | Updated
34 | 1 | R8 | Panasonic - ECG | EXB-24V104JX (http://www.mouser.com/ProductDetail/Panasonic/EXB-24V104JX/?qs=cttFivMKqWzUVL%252byMhf%252b6A%3D%3D) | RES ARRAY 100K OHM 2 RES 0404 | 100K | Updated
35 | 1 | R9 | Panasonic - ECG | EXB-24V220JX | RES ARRAY 22 OHM 2 RES 0404 | 22 | Updated
36 | 1 | R10 | Panasonic - ECG | ERJ-3EKF1004V | RES SMD 1M OHM 1% 1/10W 0603 | 1M
37 | 1 | R15 | Panasonic - ECG | EXB-N8V681JX (http://www.mouser.com/ProductDetail/Panasonic/EXB-N8V681JX/?qs=WwqriLBepZsA3j1s4S8jmg%3D%3D) | RES ARRAY 680 OHM 4 RES 0804 | 680 | Updated
38 | 1 | SW1 | HUA-JIE | TSXH-2GL | SWITCH TACTILE SPST-NO | TSXH-2GL
39 | 1 | U1 | Texas Instruments | LM3671MF-3.3/NOPB | IC REG BUCK SYNC 3.3V SOT23-5 | LM3671MF-3.3/NOPB
40 | 1 | U2 | Texas Instruments | TLV1117-50IKVURG3 | IC REG LDO 5V 0.8A TO252-3 | TLV1117-50IKVURG3
41 | 1 | U3 | Texas Instruments | LMV321IDCKR | IC OPAMP GP 1MHZ RRO SC70-5 | LMV321IDCKR
42 | 1 | U4 | STMicroelectronics | STM32F427VIT6 | IC MCU ARM 2MB FLASH 100LQFP | STM32F427VIT6
43 | 1 | Y1 | Abracon Corporation | ABM3B-25.000MHZ-D2Y-T | CRYSTAL 25.000 MHZ 18PF SMD | 25.000MHz
DO NOT PLACE
44 | 1 | J7 | FCI | 67996-206HLF | CONN HEADER 6POS .100 STR 15AU | 67996-206HLF

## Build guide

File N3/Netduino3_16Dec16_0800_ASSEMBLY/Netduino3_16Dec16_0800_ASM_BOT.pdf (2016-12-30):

ART FILM - ASM_BOT

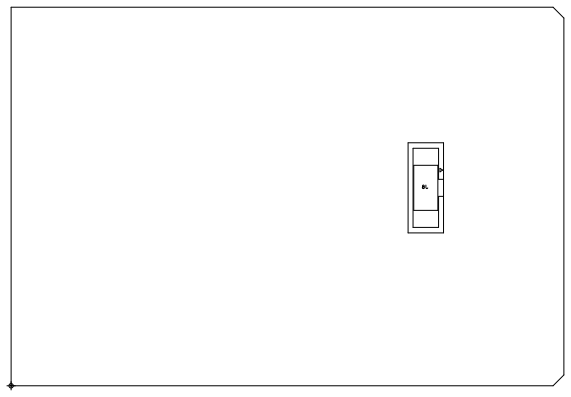
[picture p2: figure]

ART FILM - ASM_BOT

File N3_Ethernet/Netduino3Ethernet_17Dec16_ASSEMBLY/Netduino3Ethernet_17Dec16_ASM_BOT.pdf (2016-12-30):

ART FILM - ASM_BOT

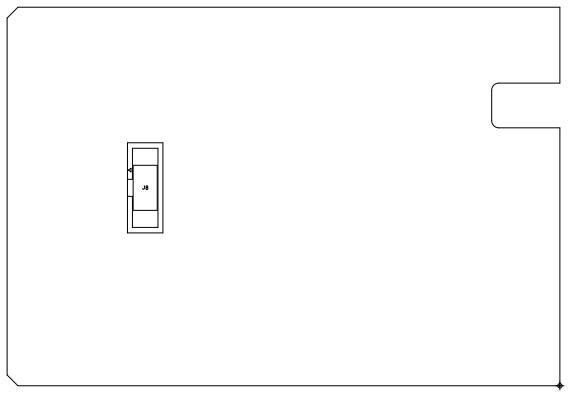
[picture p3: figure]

ART FILM - ASM_BOT

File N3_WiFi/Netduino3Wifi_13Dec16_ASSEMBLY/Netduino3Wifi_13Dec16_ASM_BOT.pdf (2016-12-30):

ART FILM - ASM_BOT

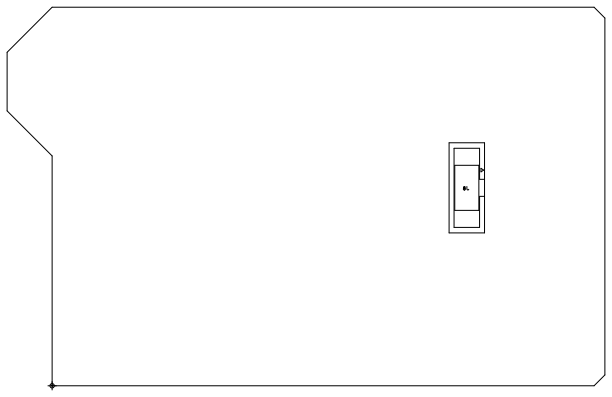
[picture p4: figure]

ART FILM - ASM_BOT

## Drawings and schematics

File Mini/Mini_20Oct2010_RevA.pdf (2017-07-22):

13 | 13 14 | 14 15 | 15 16 | 16 17 | 17 18 | 18 19 | 19 20 | 20 21 | 21 22 | 22 23 | 23 24 | 24

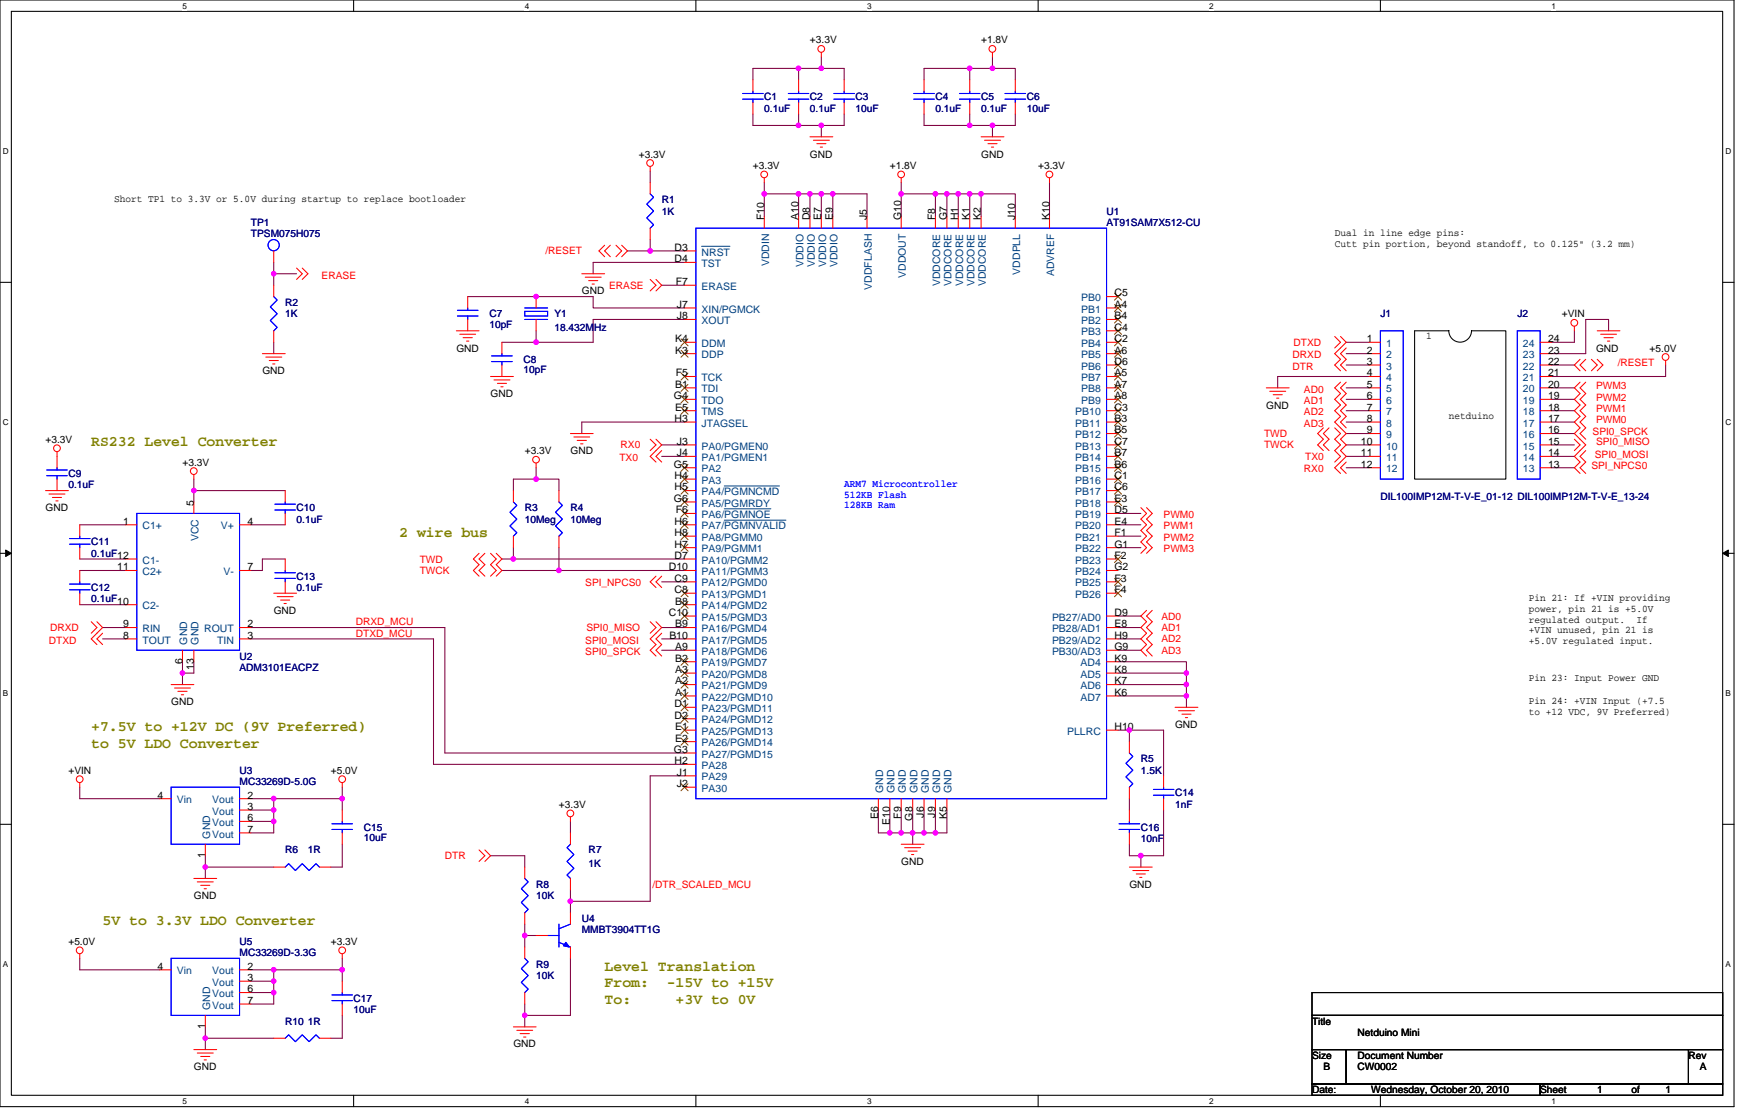
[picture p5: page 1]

Short TP1 to 3.3V or 5.0V during startup to replace bootloader

Dual in line edge pins:
Cutt pin portion, beyond standoff, to 0.125" (3.2 mm)

Pin 21: If +VIN providing
power, pin 21 is +5.0V
regulated output. If
+VIN unused, pin 21 is
+5.0V regulated input.

Pin 23: Input Power GND

Size Size Size B B B | Document Number Document Number Document Number CW0002 CW0002 CW0002 | Rev Rev Rev A A A

Date: Date: Date: Wednesday, October 20, 2010 Wednesday, October 20, 2010 Wednesday, October 20, 2010 | Sheet Sheet Sheet 1 1 1 of of of 1 1 1

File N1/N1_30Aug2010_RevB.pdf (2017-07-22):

## Power Connector +7.5V to +12V DC Input (9V Preferred)

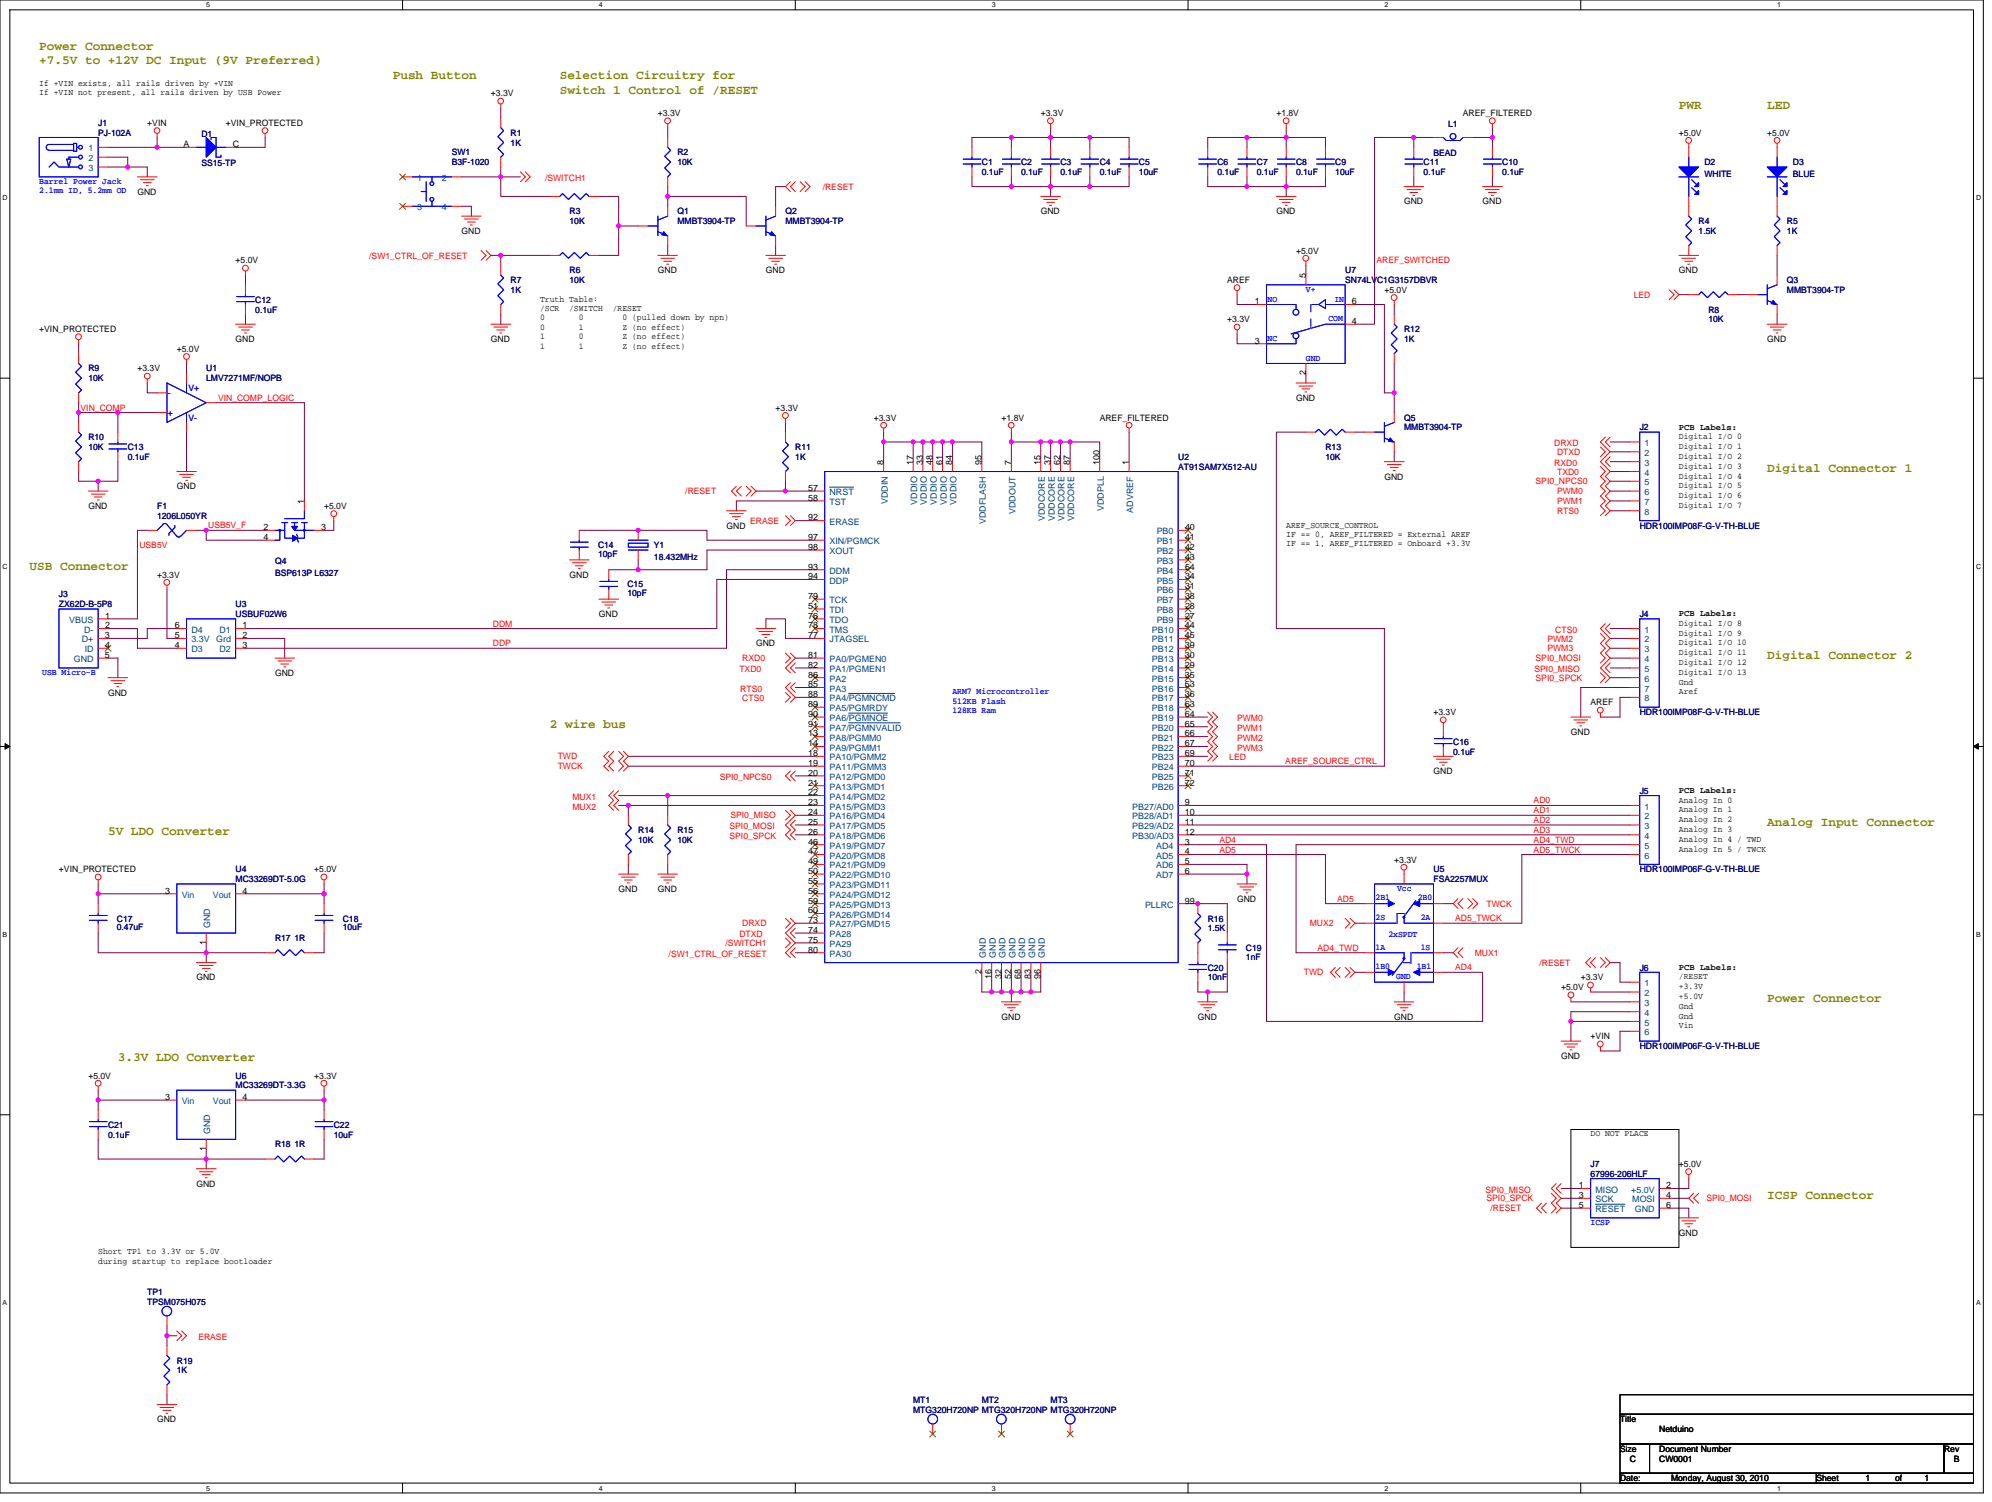
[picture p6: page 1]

Selection Circuitry for
Switch 1 Control of /RESET

If +VIN exists, all rails driven by +VIN
If +VIN not present, all rails driven by USB Power

Short TP1 to 3.3V or 5.0V
during startup to replace bootloader

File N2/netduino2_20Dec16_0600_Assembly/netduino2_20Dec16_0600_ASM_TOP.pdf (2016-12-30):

# ART FILM - ASM_TOP

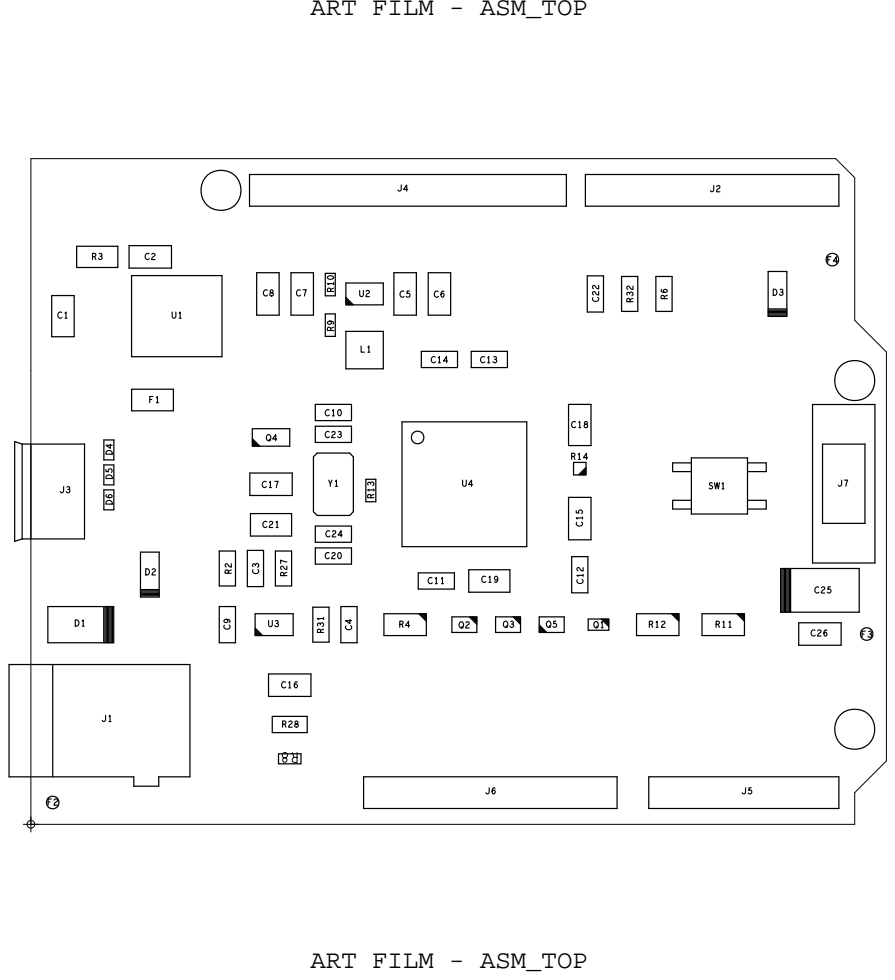
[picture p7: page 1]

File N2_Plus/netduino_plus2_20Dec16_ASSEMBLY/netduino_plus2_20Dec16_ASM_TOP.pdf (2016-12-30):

# ART FILM - ASM_TOP

## J2 SW1

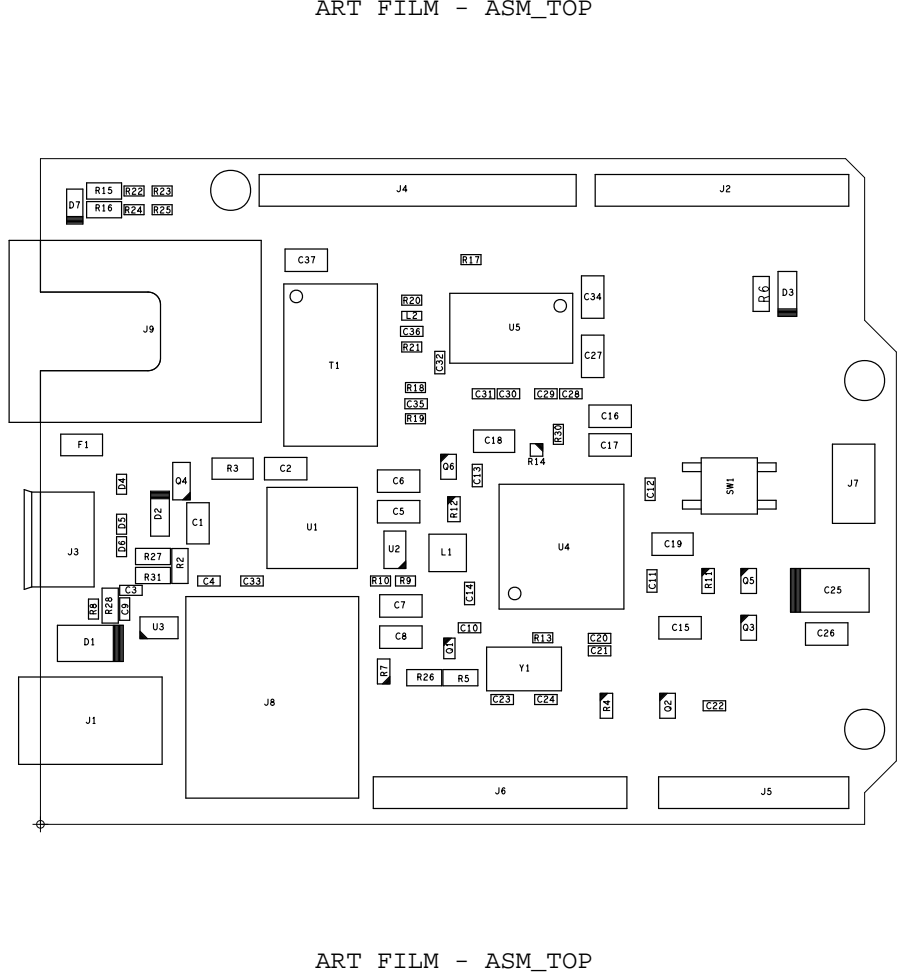
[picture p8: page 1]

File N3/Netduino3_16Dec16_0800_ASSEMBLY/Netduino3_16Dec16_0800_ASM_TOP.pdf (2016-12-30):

# ART FILM - ASM_TOP

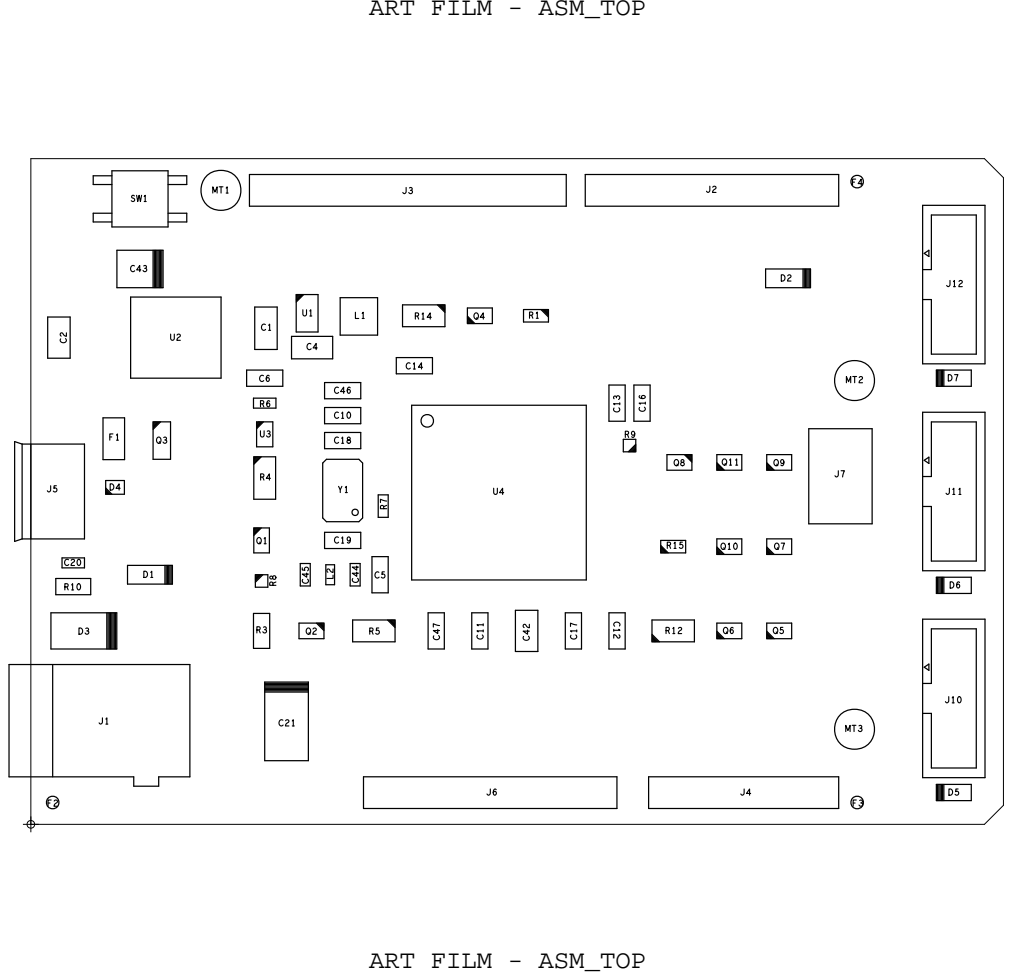
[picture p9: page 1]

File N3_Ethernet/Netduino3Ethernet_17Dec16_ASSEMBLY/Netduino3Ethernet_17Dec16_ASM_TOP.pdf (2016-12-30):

# ART FILM - ASM_TOP

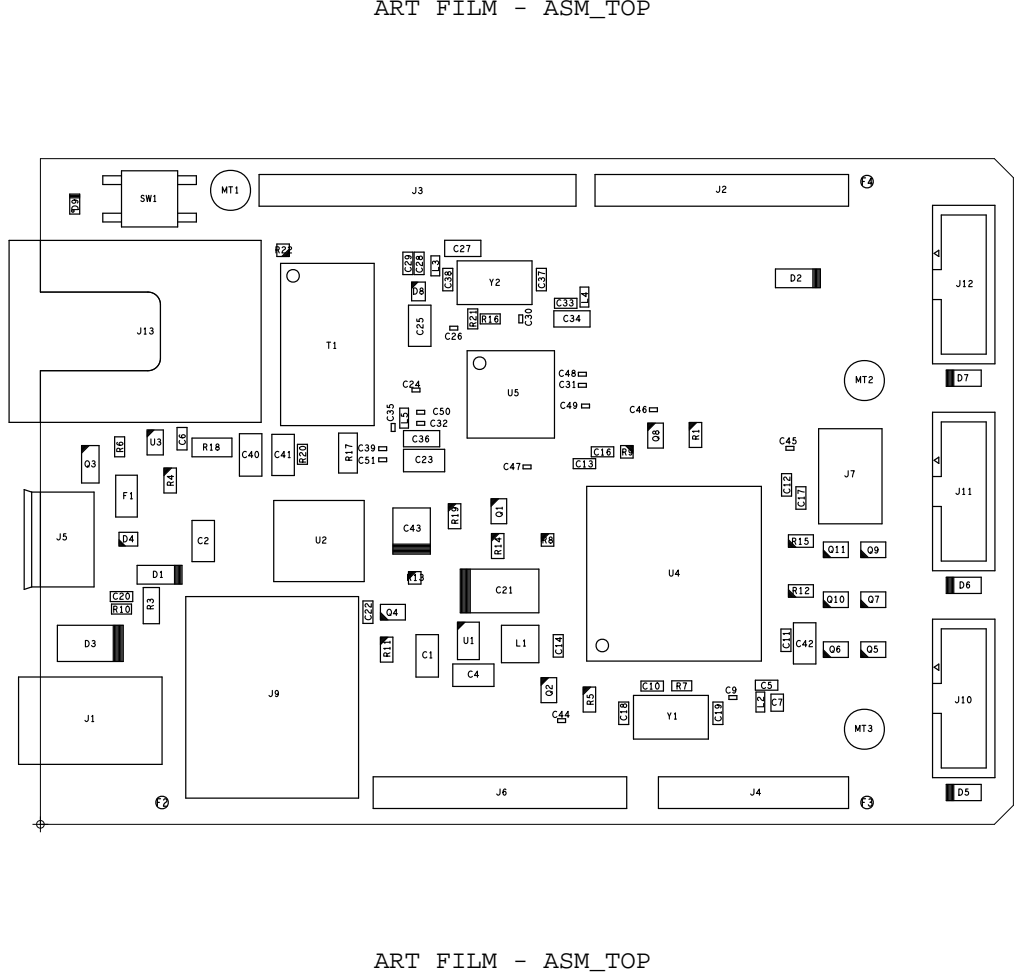
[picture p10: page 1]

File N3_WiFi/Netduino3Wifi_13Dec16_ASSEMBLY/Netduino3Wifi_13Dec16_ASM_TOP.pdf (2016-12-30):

# ART FILM - ASM_TOP

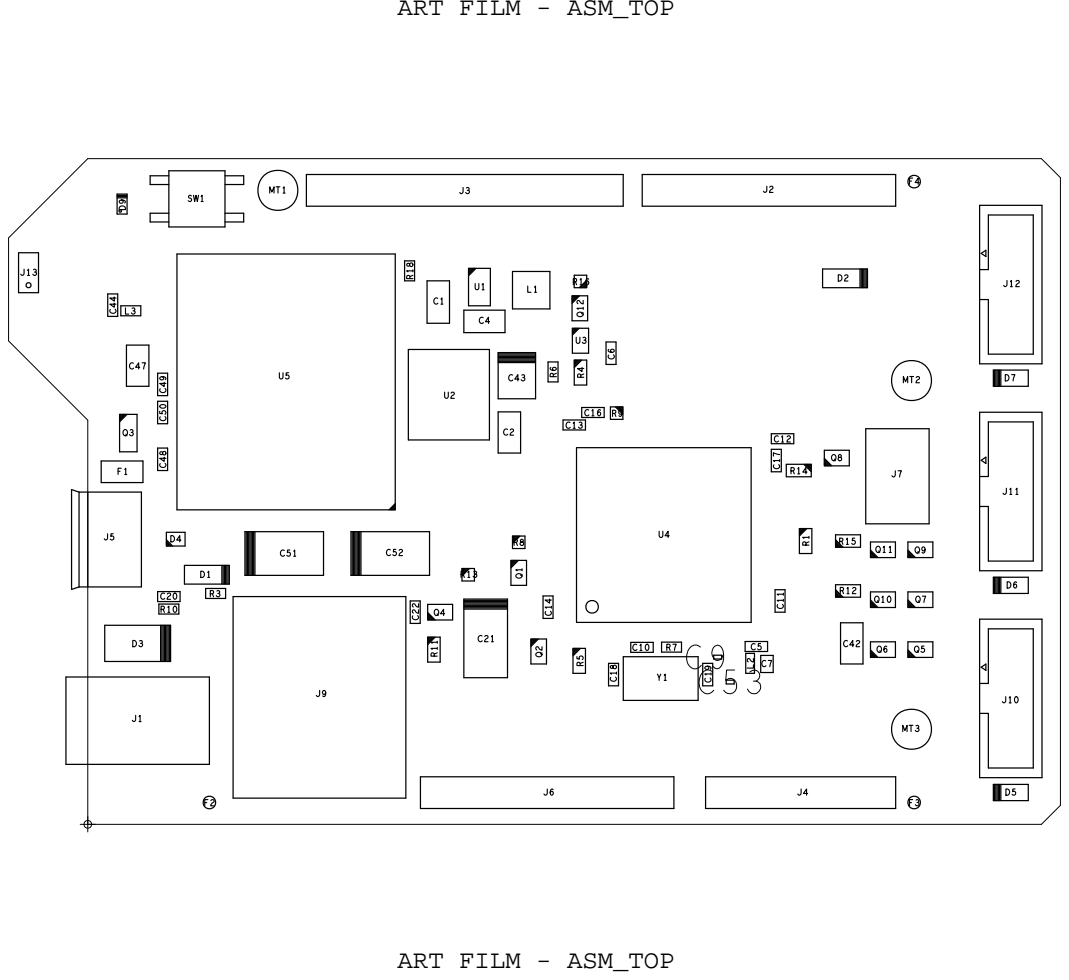
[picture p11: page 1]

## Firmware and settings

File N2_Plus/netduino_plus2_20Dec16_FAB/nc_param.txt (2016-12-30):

INTEGER-PLACES         2
DECIMAL-PLACES         5
X-OFFSET               0.000000
Y-OFFSET               0.000000
FEEDRATE               1
COORDINATES            ABSOLUTE
OUTPUT-UNITS           METRIC
TOOL-ORDER             INCREASING
REPEAT-CODES           YES
SUPPRESS-LEAD-ZEROES   NO
SUPPRESS-TRAIL-ZEROES  NO
SUPPRESS-EQUAL         NO
TOOL-SELECT            NO
OPTIMIZE_DRILLING      NO
ENHANCED_EXCELLON      NO
HEADER                 none
LEADER                 12
CODE                   ASCII
SEPARATE               NO
SEPARATE-ROUTING       NO
DRILLING               LAYER-PAIR
BACKDRILL              NO
CAVITY                 NO

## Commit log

2016-12-30 Initial check in
    [E3_ETHENET_BOM-17DEC16.xlsx, N2_20DEC16.DSN, N2_20DEC16.xlsx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]
2016-12-31 Getting rid of garbage mac files with carriage returns in their nam
2017-04-13 Added panelized gerbers
2017-04-25 renamed dirs and fixed links
    [E3_ETHENET_BOM-17DEC16.xlsx, N2_PLUS_20DEC16.xlsx, N2_PLUS_20DEC16_0800.DSN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]
2017-05-11 added panelized gerbers.
2017-06-01 Fixed part on BOM to have the correct footprint
    [N3_WIFI_BOM_13Dec16.xlsx]
2017-06-08 removed duplicate BOM and added DNI to components
    [E3_ETHENET_BOM-17DEC16.xlsx]
2017-06-23 Added DNI to MiniJTAG connector
    [N3_WIFI_BOM_13Dec16.xlsx]
2017-07-22 Added legacy N1, N1+ and Mini Files
    - Added schematics and brd design files for N1, N1+ and Mini
    - Updated ReadMe
    [Netduino.brd, NetduinoMini.brd, NetduinoPlus.brd]
2017-09-09 Added Netduino Go schematic.
